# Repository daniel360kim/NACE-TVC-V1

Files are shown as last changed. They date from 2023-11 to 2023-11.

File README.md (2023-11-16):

<!-- PROJECT LOGO -->
<br />
<div align="center">
  <a href="https://github.com/daniel360kim/NACE-TVC-V1">
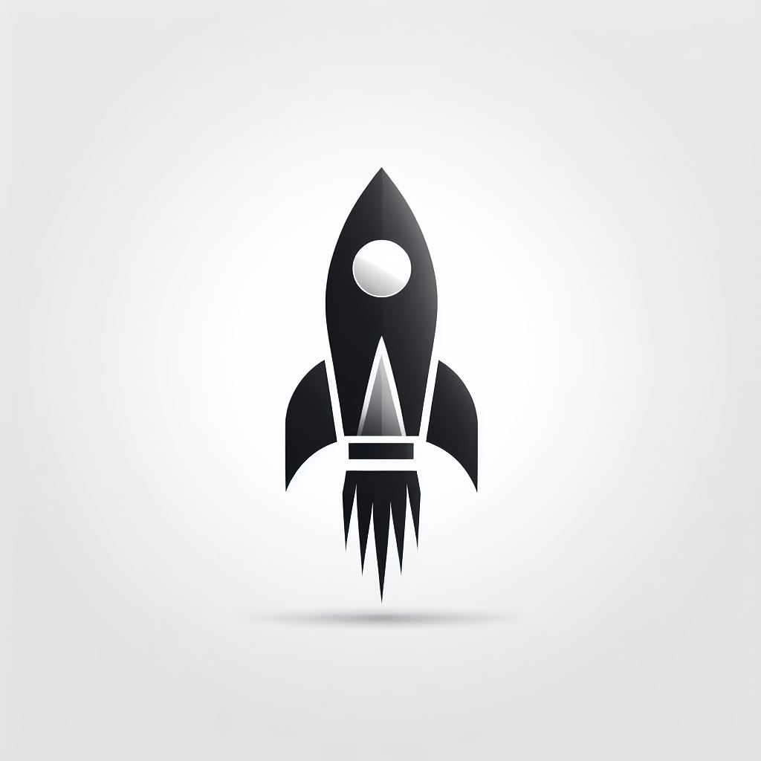
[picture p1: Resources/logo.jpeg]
    
  </a>

  <h3 align="center">NACE Thurst Vector Control</h3>

  <p align="center">
    An awesome README template to jumpstart your projects!
    <br />
    <a href="https://youtu.be/ad6DS7cMQtw?si=ODGq_ugdBTZ1fljK"><strong>Watch the video »</strong></a>
    <br />
    <a href="https://www.nmas.org/wp-content/uploads/2023/03/2022_NMJS_Kim.pdf"><strong>Read the publication »</strong></a>
    <br />
    <br />
    <a href="https://github.com/daniel360kim/NACE-TVC-V1/tree/v2.2/FlightSoftware">Flight Software</a>
    ·
    <a href="https://github.com/daniel360kim/NACE-TVC-V1/tree/v2.2/Simulation">Simulation</a>
    ·
    <a href="https://github.com/daniel360kim/NACE-TVC-V1/tree/v2.2/CAD">CAD</a>
  </p>
</div>

<!-- ABOUT THE PROJECT -->
## About The Project
<div align="center">
  <a href="https://github.com/daniel360kim/NACE-TVC-V1">
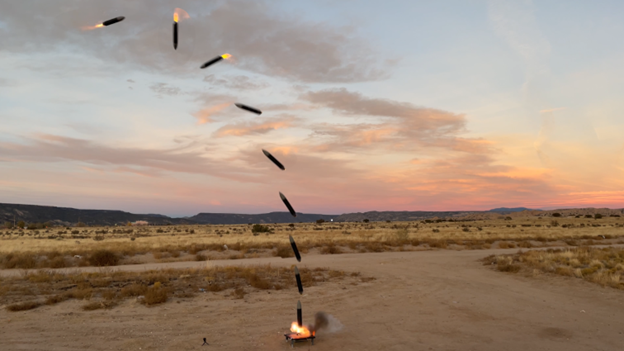
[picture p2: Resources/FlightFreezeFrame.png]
    
  </a>
</div>

There are so many thrust vector controlled model rocket projects out there, but none of them are open source. This project aims to change that. This project is open source and is meant to be a resource for anyone who wants to build a thrust vector controlled model rocket. This project is also meant to be a resource for anyone who wants to learn about thrust vector control.

Here's why I decided to make this project:
* Wanted to explore the world of control algorithms
* Real-time control algorithms are soo cool
* I love to learn :)

<p align="right">(<a href="#readme-top">back to top</a>)</p>

### Built With
* [PlatformIO](https://platformio.org/)
* [Arduino](https://www.arduino.cc/)
* [Simulink](https://www.mathworks.com/products/simulink.html)
* [EasyEDA](https://easyeda.com/) (yes I have switched to KiCAD)

### Building the flight software in PlatformIO
1. Install [PlatformIO](https://platformio.org/)
2. Clone the repo
   ```sh
   git clone https://github.com/daniel360kim/NACE-TVC-V1.git
    ```
3. Open the project in PlatformIO
4. Build the project

See? Super-duper easy with PlatformIO. It will also automatically install all the dependencies for you!

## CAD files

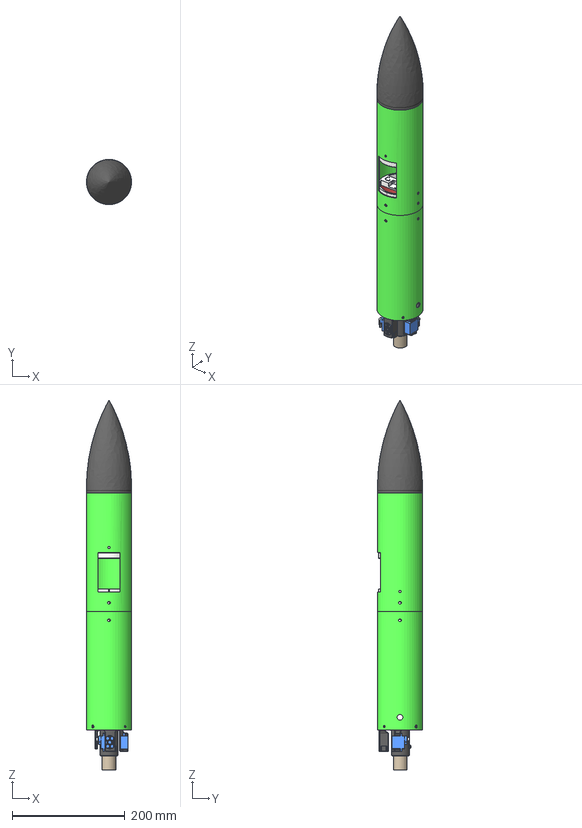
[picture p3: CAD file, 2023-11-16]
CAD/Rocket/TVC Rocket rev2.step
80.0 x 80.0 x 655.9 mm
servo
splined-drive
horn
servo (1)
splined-drive (1)
horn (1)
Lower Body
Coupling
NACE Mount Bottom (1)
Upper Body (1)
NoseConeNew v1
Estes D12
PyroSeal

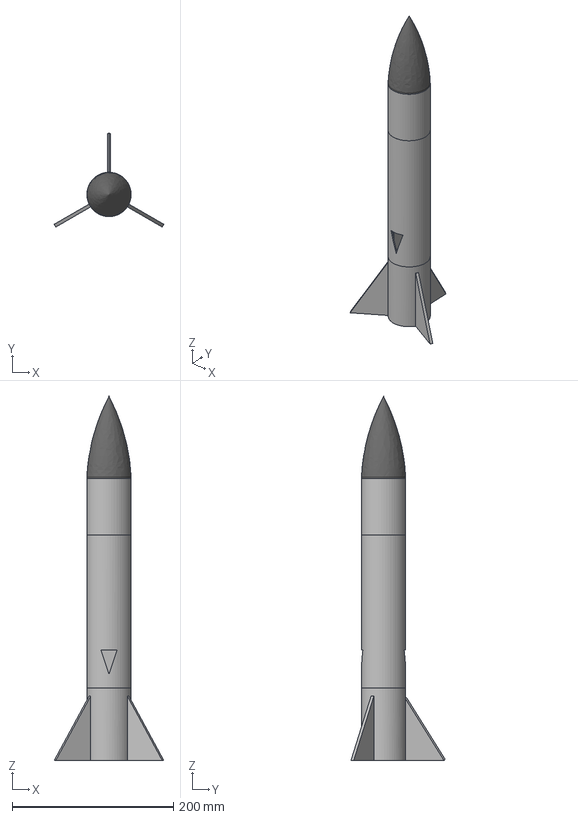
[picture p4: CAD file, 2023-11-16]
CAD/Rocket/Datalog Rocket.step
136.2 x 116.9 x 452.0 mm
Motor Mount Screw
Motor Rings
UpperTopBody
Mount holder
PCBv2
Nosecone Datalog
Bulkhead

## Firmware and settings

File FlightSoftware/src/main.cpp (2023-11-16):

#include <Arduino.h>
#include <Servo.h>
#include <Outputs.h>
#include <Navigation.h>
#include <SDcard.h>
#include <PID.h>

void setup() { //runs once at the beginning
 initializeOutputs();
 startupSequence();
 initializeSensors();
 initializeSD();
 indicateCompleteStartup();
 previous_time = micros(); //allows for smooth data and acc. pos/vel measurements at the beginning 
 systemState = 0;
}

void loop() { //runs continuously after setup

//calculating dt which is used very frequently throughout the different headers
 unsigned long microseconds = micros();
 dt = (microseconds - previous_time) / 1000000.f;
 previous_time = microseconds;

 readSensors(); //collect sensor data
 FlightTime(); //run timekeeper

 ////////States Machine////////////////
 if(systemState == 0){ //launchpad idle/ground startup
     allPyrosLow();
     slowDataLog();
     displaySpectrum();
     //errorCheckIMU(); //exit condition 1
     detectNavReady(); //exit condition 2
     Serial.println("SS: 0");
 }
 
 if(systemState == 1){ //waiting for a launch
     allPyrosLow();
     slowDataLog();
     detectLaunch(); //exit condition
     displaySpectrum();
 }
 if(systemState == 2){//powered flight
     runPID();
     Flight_Termination_Handler();
     fastDataLog();
     setColor(0,255,238); //sky blue
     detectBurnout(); //exit condition
   
 }
 else if(systemState == 3){ //unpowered flight
     runPID();
     fastDataLog();
     setColor(255,213,0); //yellow
     detectApogee(); //exit condition
     
 }
 else if(systemState == 4){ //descent
     detachServos();
     fileCloseandOpen(); //saves data in case of corruption or loss of data on "landing" ascent is mostly the data we need, but descent is usefull too
     fastDataLog();
     setColor(0,255,60); //spring green
     detectLanding();

 }
 else if(systemState == 5){ //landed
     indicateLanding();
     slowDataLog(); //although landing was detected, we slow datalog in case of mistriggered exit state 

 }


 if(systemState == 6){//abort called
     closeFile();
     setColor(255,0,0);

 }
    Serial.println(data.altitude);
}

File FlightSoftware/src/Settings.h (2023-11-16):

/*
Most of the settings that can be changed before the flight
Some changeable settings are just kept within functions because they are rarely (probably never) changed
*/

#ifndef Settings_h
#define Settings_h

  #define Gravity 9.80665f
  
  ///PID Gains that are tuned 
  const float kp = 0.3;
  const float ki = 0.4;
  const float kd = 0.07;
  
  //Gear ratio between servos and tvc mount
  const int gearRatio = 2;

  //output limits of the servo motors limited by the TVC mount
  const int outputLimitHigh = 10;
  const int outputLimitLow = -10;
  
  //the angle that the rocket is pointing (always zero or straight)
  const uint8_t Setpoint = 0;
  
  //abort is pretty much useless right now so we have it disabled
  bool abort_armed = false;

  //logging rate of the SD card
  unsigned long fastlogPeriodMicros = 500000; //50hz
  unsigned long slowlogPeriodMicros = 1000000; //1hz

  //Offsets for tuning
  const float servoY_offset = 93;
  const float servoX_offset = 99; //plus for counter negative for clockwise
  //Position of servos through the startup function
  int servoXstart = servoY_offset * -1;
  int servoYstart = servoX_offset;
  //Ratio between servo gear and tvc mount
  const float servoX_gear_ratio = 2;
  const float servoY_gear_ratio = 2;

  uint8_t velocityTerminationThreshold = 1; //at what velocity do we stop startup on the launchpad

  //abort settings
  bool enableFTS = false;//enable the flight termination system
  uint8_t abort_threshold = 40; //what angle we call an abort during flight
  float pyOnTimeSec = 0.25; //how long the pyro is on for
 
  //intervals at which the intervals aere checked for apogee detection - so random noise doesn't accidentally trigger system exit function
  const unsigned long bmpInterval = 250000;
  const unsigned long apogeeCheck = 250000;

  //if the gyro threshold is not triggered for a set amount of time, we call a landing anyway as a failsafe
  const unsigned long landingDelayTime = 10000000; //10 seconds

  uint8_t systemState = 0; //state machine variable - just put it here in case we want to change it for some reason during testing...
   
  #endif

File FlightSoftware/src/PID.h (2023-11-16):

/*
PID controller. This is the control algorithm that outputs the angle needed by the TVC mount to correct the error. 
*/
#ifndef PID_h
#define PID_H

#include <Navigation.h>
#include <Settings.h>
#include <Outputs.h>

//"PID" Constants - These are always changing
float X_p = 0;
float Y_p = 0;
float Y_i = 0;
float X_i = 0;
float X_d = 0;
float Y_d = 0;

float previous_errorX, previous_errorY; //Previous errors - used for the integral

float PIDX, PIDY; //pid outputs

void convert_to_vehicle(){ //converting pid angles so that it accounts for roll: pitch and yaw are decoupled from roll using this function 
    float cs = cos(data.X * DEG_TO_RAD);
    float sn = sin(data.X * DEG_TO_RAD);
 
    data.PIDY = (PIDX * sn) + (PIDY * cs);
    data.PIDX = (PIDX * cs) - (PIDY * sn);
}

void runPID() { //two variations for each axis
    //finding the error
    data.errorX = -1 * (data.Y - Setpoint); 
    data.errorY = -1 * (data.Z - Setpoint);
    
    //proportional gain
    X_p = kp * data.errorX;
    Y_p = kp * data.errorY;
    
    //Integral gain
    X_i = ki * (X_i + data.errorX * dt);
    Y_i = ki * (Y_i + data.errorY * dt);
    
    //Derivative gain
    X_d = kd * ((data.errorX - previous_errorX) / dt);
    Y_d = kd * ((data.errorY - previous_errorY) / dt);
    
    //adding all the constants up
    PIDX = X_p + X_i + X_d;
    PIDY = Y_p + Y_i + Y_d;
    
    //adding the offsets and ratios to the output
    float pwmY = ((data.PIDY * servoY_gear_ratio) + servoY_offset);
    float pwmX = ((data.PIDX * servoX_gear_ratio) + servoX_offset);  

    //writing the data to the servos!
    ServoXYwrite(pwmX, pwmY);

    previous_errorX = data.errorX;
    previous_errorY = data.errorY;
}

#endif

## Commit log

2021-11-05 problems with acc readings
    [main.cpp]
2022-05-29 NACE fc upload
    Schematic and PCB files for the flight computer used for this project.
    [PCB_NACE V2_2021-09-25.pcbdoc, Sheet_1_2021-09-25.schdoc]
2023-11-16 reordered directories
    [Datalog Rocket.step, PCB_NACE V2_2021-09-25.pcbdoc, Sheet_1_2021-09-25.schdoc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]
